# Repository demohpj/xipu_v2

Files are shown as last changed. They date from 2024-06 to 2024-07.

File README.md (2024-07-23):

# XiPU_v2

XiPU_v2 is an 8-bit 7400 TTL CPU project. It is a second iteration of the XiPU project.

## 1. About the project

The XiPU_v2 is loosely based on MOS 6502 and early x86. It was my starting point of design my own CPU. For now, the XiPU_v2 has many differences and it is so much simpler than those CPUs.

The second version of the XiPU has extended instruction set, new flat memory structure, advanced stack and function frame operations support.

The main goal of the project is creating a fully functional 8-bit 7400 TTL CPU and a simple computer based on the one.

### 1.1. Author

- Pawel Jablonski (pj@xirx.net)

### 1.2. License

You can use this code however you like but leave information about the original author. Code is free for non-commercial and commercial use.

Please see the LICENSE.txt file.

### 1.3. Links

- WWW: [xirx.net](https://xirx.net "xirx.net")
- GIT: [git.xirx.net](https://git.xirx.net "git.xirx.net")

## 2. Useful knowledge

### 2.1. Dictionary

- XiPU - XiRX Processor Unit. The name of the 8-bit TTL CPU.
- XiPU_v2 - The second iteration of the XiPU.
- XiPC - XiRX Personal Computer. The name of the simple computer based on XiPU CPU
- TTL - Transistor-transistor logic.
- HCT - High-Speed CMOS chips available in TTL compatible form.
- RAM - Volatile random access memory.
- ROM - Non-volatile read-only memory.
- Register - Quickly accessible location for a small amount of data stored in a TTL chip.
- uROM - uROM determines which of the internal registers is used to read from and write to at the current micro step of executing instruction.
- BIOS - Basic input/output system. Provides access to basic IO API and loads the OS.
- OS - Operating System. It contains a terminal interface and basic libraries.
- Stack - High accessibly memory page where data is stored as FILO.
- Function Frame - Part of the stack where arguments of the function and local variables are stored.
- IO operation - Read or write data to pins connected to external world.
- External BUS - Data highway for IO operations.
- ALU - Arithmetic logic unit.

### 2.2. XiPU_v2

- 8-bit processor based on 7400 HCT chips compatible with TTL.
- 64 kB of RAM space. Lower 2 kB are reserved for BIOS stored at EEPROM. The 4 kB at the end of the memory are used as a stack. Rest 58 kB of memory could be used by OS or applications.
- 1 MHz clock speed. The processor uses a 2 MHz crystal to get two 1 MHz square waves shifted relative to the other about half.
- The processor uses uROM stored in two EEPROMs.
- Each instruction could be built from 2 to 16 micro steps. Each micro step takes exactly 1 clock tick.
- Four registers:
	- A, B - 8-bit general purpose registers.
	- X, Y - 8-bit auxiliary registers. Could be used mostly as general purpose registers. Together, it can be used as a 16-bit address register.
- Two hidden stack registers:
	- SP - Stack Pointer. It is used to address the head of the stack.
	- BP - Base Pointer. It is used to address the function frame on the stack to store parameters of a function and local variables.
- Three internal buses:
	- BUS A - 8-bit main BUS for registers, RAM, ROM, IO operations.
	- BUS B - 8-bit auxiliary BUS for registers used as second input for ALU.
	- BUS C - 16-bit memory address BUS for addressing RAM.
- 8-bit IN and 8-bit OUT external data BUS. It is used as a simple communication way with the external word.

### 2.3. XiPC

- Personal computer based on the XiPU.
- 40x30 characters with 16 colors support. It uses 640x480 LCD with an 8-bit color palette to render image output.
- Mono speaker with a volume knob.
- RS-232 with 1200 bps support.
- RTC with battery support.
- Built-in QWERTY keyboard.
- 4 status LEDs.
- 7.5V max 1.0A power supply.

## 3. Project overview

### 3.1. Requirements

The project supports building process on Windows and Linux.

- Geany - Multi-language IDE. Used to create Makefile, assembler code etc.
- QtCreator - IDE for C++/Qt. Used to create desktop applications.
- Qt 5.12.4 - Multiplatform Qt 5 library. It supports UI, data structures, files etc.
- GCC - C and C++ code compiler.
- Keil uVision 5.37 - Compiler and debugger for the STM32F0 MCU.
- Make - Build automation tool.
- Doxygen 1.9.7 - Documentation generator from annotated sources.
- Proteus 8.10 - Circuit simulator software. Used to simulate the XiPU.
- QCAD - DXF files editor. Used to create Plexiglas case for the XiPC.
- DipTrace 4.2.0.1 - Schematic and PCB design software.

### 3.2. Project structure

```console
.
├── LICENSE.txt    # License file.
├── Makefile       # Main Makefile file to building binaries and documentations at once.
├── README.md      # Readme file.
├── bin            # Destination directory for all generated binaries during the build process.
├── case
│   ├── 3d         # A 3D printed case project for the XiPC.
│   └── plexiglass # A simple Plexiglas case project for the XiPC.
├── cpu
│   ├── bios       # BIOS with a loader and IO API for the OS.
│   ├── pcb        # PCB design for the XiPU.
│   └── sim        # Simulation project of the XiPU.
├── doc            # Destination directory for all generated documentations during the build process.
├── ide
│   ├── geany      # IDE configuration to support assembler for the XiPU.
│   └── qtcreator  # IDE configuration for code rules.
├── io
│   ├── fw         # Firmware for the IO Board.
│   └── pcb        # PCB design for the IO Board.
├── kbd
│   └── pcb        # PCB design for the Keyboard.
├── sys
│   ├── app        # Applications written for the XiPC.
│   ├── fs         # File System generator needed by the real XiPC and the XiPC Emulator.
│   └── os         # OS with a simple terminal and basic libraries for applications.
└── tools
    ├── asm        # Assembler Compiler.
    ├── emu        # XiPC Emulator.
    ├── fonts      # Fonts used in desktop GUI applications.
    ├── lib        # Binary libraries needed to run compiled applications on Windows x64.
    └── urom       # uROM generator.
```

## 4. Compiling

### 4.1. Build all

To build all binaries and create documentations for them, please type:

```console
make
```

### 4.2. Build a single module

#### 4.2.1 uROM

To build the application and create documentation, please type:

```console
cd tools/urom
make
```

#### 4.2.2. ASM Compiler

To build the application and create documentation, please type:

```console
cd tools/asm
make
```

#### 4.2.3. BIOS

To build the BIOS image file, the map file with API handlers, and create documentation, please type:

```console
cd cpu/bios
make
```

#### 4.2.4. OS

To build the OS, the map file with API handlers, please type:

```console
cd sys/os
make
```

#### 4.2.5. IO Board firmware

To build the IO Board firmware file, and create documentation, please type:

```console
cd io/fw
make
```
To build successfully a firmware is needed the Keil uVision5 with a free license for STM32F0 MCU. UV4.exe must be added to the PATH env.

#### 4.2.6. Applications

To build the user applications, please type:

```console
cd sys/app
make
```

#### 4.2.7. File System

To generate a directory with the virtual file system, please type:

```console
cd sys/fs
make
```

#### 4.2.8. XiPC Emulator

To build the application and create documentation, please type:

```console
cd tools/emu
make
```

## 5. Using

### 5.1. uROM

To generate uROM files, please type:

```console
./urom
```

### 5.2. ASM Compiler

To compile BIOS, please type:

```console
./asm bios [input_file] [output_bin] [output_map]
```

To compile OS, please type:

```console
./asm os [input_file] [output_bin] [output_map]
```

To compile an application, please type:

```console
./asm app [input_file] [output_bin]
```

#### 5.3. XiPC Emulator

To run the XiPC Emulator application, please type:

```console
./emu
```

It will show a window of the emulator ready to work. Next step is loading uROM files, BIOS file and choose the directory with the virtual file system. After that, the application is ready to run emulation.

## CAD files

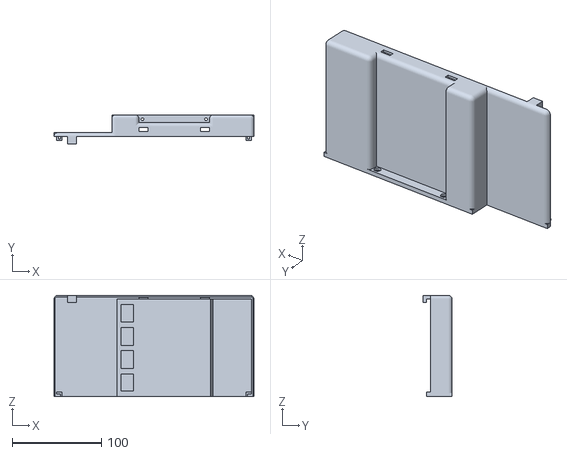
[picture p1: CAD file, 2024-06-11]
case/3d/stl/lcd_back.stl
224.6 x 32.8 x 113.5

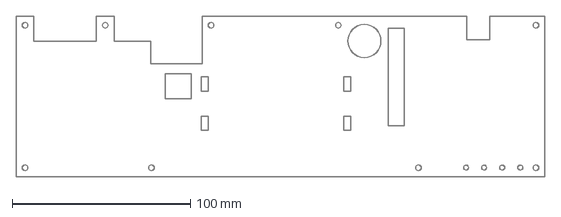
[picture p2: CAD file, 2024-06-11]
case/plexiglass/io.dxf
297.0 x 90.0 mm

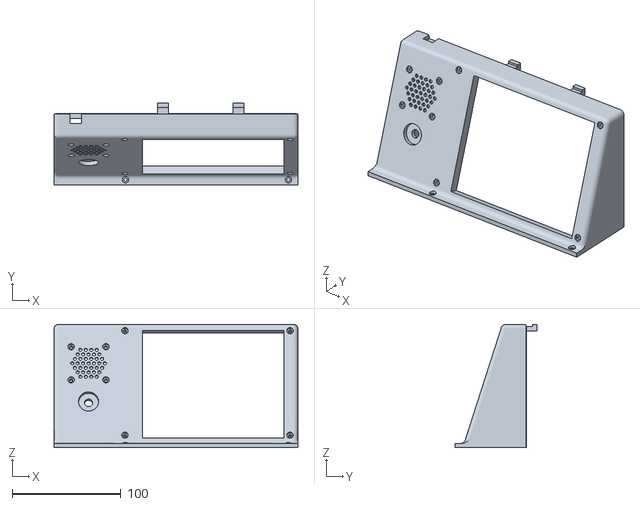
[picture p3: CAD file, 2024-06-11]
case/3d/stl/lcd_front.stl
224.6 x 75.3 x 113.5

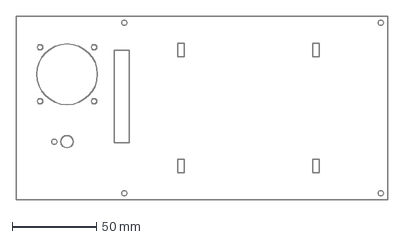
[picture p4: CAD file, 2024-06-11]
case/plexiglass/lcd.dxf
220.0 x 109.0 mm

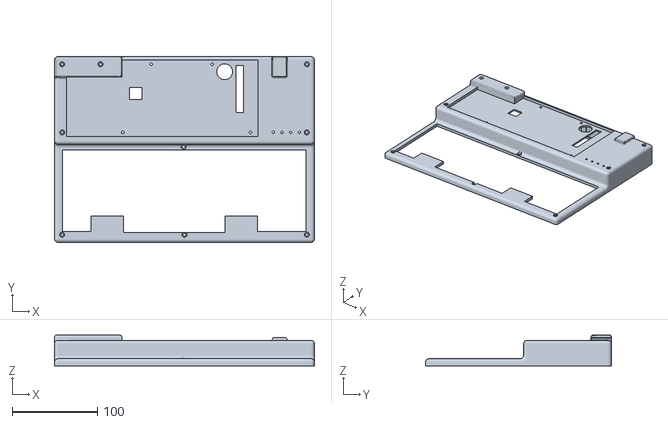
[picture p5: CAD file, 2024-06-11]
case/3d/stl/top.stl
305.0 x 218.0 x 36.0

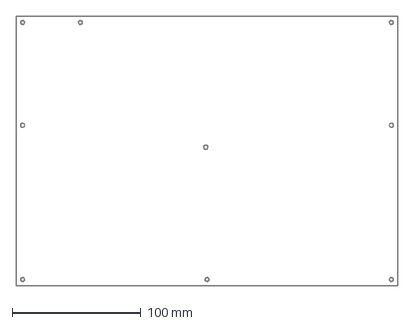
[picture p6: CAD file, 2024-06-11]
case/plexiglass/xipu.dxf
297.0 x 210.0 mm

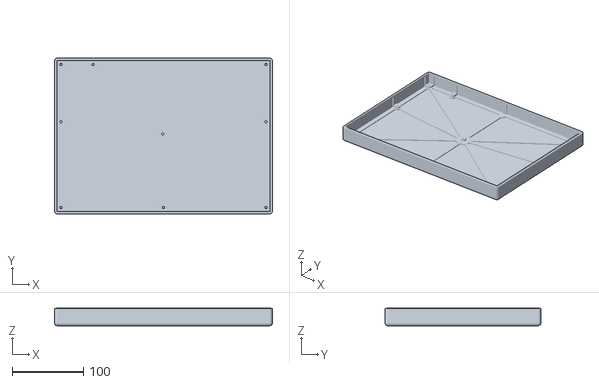
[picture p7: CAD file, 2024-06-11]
case/3d/stl/bottom.stl
305.0 x 218.0 x 24.7

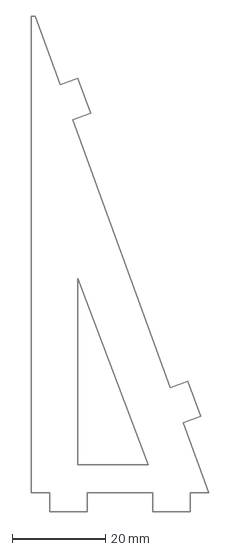
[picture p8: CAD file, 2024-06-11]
case/plexiglass/support.dxf
38.0 x 106.0 mm

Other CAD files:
case/3d/f3d/bottom.f3d
case/3d/f3d/lcd_back.f3d
case/3d/f3d/lcd_front.f3d
case/3d/f3d/top.f3d

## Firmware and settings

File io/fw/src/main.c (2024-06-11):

/*
 * Author: Pawel Jablonski
 * E-mail: pj@xirx.net
 * WWW: xirx.net
 * GIT: git.xirx.net
 *
 * License: You can use this code however you like
 * but leave information about the original author.
 * Code is free for non-commercial and commercial use.
 */

#include <stm32f0xx.h>
#include <stm32f0xx_hal.h>
#include <stm32f0xx_hal_gpio.h>
#include <stm32f0xx_hal_rcc.h>
#include <system_stm32f0xx.h>

#include "type.h"
#include "led.h"
#include "rtc.h"
#include "keyboard.h"
#include "speaker.h"
#include "lcd.h"
#include "flash.h"
#include "io.h"
#include "rs232.h"
#include "usb.h"
#include "fs.h"

bool initIsEnded = FALSE; //!< Status of end initializing all devices

//! Init main clock
static void initClock(void)
{
	RCC_OscInitTypeDef oscInit;

	oscInit.OscillatorType = (RCC_OSCILLATORTYPE_HSE | RCC_OSCILLATORTYPE_LSE);
	oscInit.HSEState = RCC_HSE_ON;
	oscInit.HSICalibrationValue = 16;
	oscInit.LSEState = RCC_LSE_ON;
	oscInit.PLL.PLLState = RCC_PLL_ON;
	oscInit.PLL.PLLSource = RCC_PLLSOURCE_HSE;
	oscInit.PLL.PLLMUL = RCC_PLL_MUL6;
	oscInit.PLL.PREDIV = RCC_PREDIV_DIV1;
	
	if(HAL_RCC_OscConfig(&oscInit) != HAL_OK)
	{
		while(1);
	}
	
	RCC_ClkInitTypeDef clkInit;
	
	clkInit.ClockType = (RCC_CLOCKTYPE_SYSCLK | RCC_CLOCKTYPE_HCLK | RCC_CLOCKTYPE_PCLK1);
	clkInit.SYSCLKSource = RCC_SYSCLKSOURCE_PLLCLK;
	clkInit.AHBCLKDivider = RCC_SYSCLK_DIV1;
	clkInit.APB1CLKDivider = RCC_HCLK_DIV1;
	
	if(HAL_RCC_ClockConfig(&clkInit, FLASH_LATENCY_1) != HAL_OK)
	{
		while(1);
	}

	__HAL_RCC_SYSCFG_CLK_ENABLE();
	
	HAL_SYSTICK_Config(HAL_RCC_GetHCLKFreq() / 1000);
	HAL_SYSTICK_CLKSourceConfig(SYSTICK_CLKSOURCE_HCLK);

	HAL_NVIC_SetPriority(SysTick_IRQn, 0, 0);
}

//! Main clock ticks handler. It executes a fire function if the time counter reach maximum delay for connected device.
void SysTick_Handler(void)
{	
	HAL_IncTick();
	
	if(initIsEnded)
	{
		static unsigned long long time = 0;
		
		if((time % KEYBOARD_FIRE_DELAY) == 0) keyboardFire();
		if((time % IO_FIRE_CLOCK_DELAY) == 0) ioFireClock();
		if((time % IO_FIRE_PERIPHERIAL_DELAY) == 0) ioFirePeripherial();

		time++;
	}
}

//! Main entry function of the firmware
int main(void)
{
	HAL_Init();
	
	initClock();
	
	ioPreInit();
	
	ledInit();
	rtcInit();
	keyboardInit();
	speakerInit();
	lcdInit();
	flashInit();
	rs232Init();
	usbInit();
	fsInit();
	ioInit();
	
	initIsEnded = TRUE;
	
	lcdDrawLoop();
	
	// Do not allow returning from the main function
	while(TRUE);
		
	return(0);
}

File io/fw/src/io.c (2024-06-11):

/*
 * Author: Pawel Jablonski
 * E-mail: pj@xirx.net
 * WWW: xirx.net
 * GIT: git.xirx.net
 *
 * License: You can use this code however you like
 * but leave information about the original author.
 * Code is free for non-commercial and commercial use.
 */

#include <stm32f0xx.h>
#include <stm32f0xx_hal.h>
#include <stm32f0xx_hal_gpio.h>
#include <stm32f0xx_hal_rcc.h>
#include <system_stm32f0xx.h>

#include "type.h"
#include "keyboard.h"
#include "led.h"
#include "lcd.h"
#include "rs232.h"
#include "rtc.h"
#include "speaker.h"
#include "fs.h"

#include "io.h"

#define HALF_LOW FALSE //!< Low half of data transfer
#define HALF_HIGH TRUE //!< High half of data transfer

#define MODE_REG_SELECT FALSE //!< Register select mode
#define MODE_DATA_TRANSFER TRUE //!< Data transfer mode

#define RW_READ FALSE //!< Read data mode
#define RW_WRITE TRUE //!< Write data mode

//! Register addresses
enum RegAddress
{
	REG_COMMAND = 0, //!< Command register
	REG_STATUS = 1, //!< Status register
	REG_FIELD_ADDRESS = 2, //!< Field address register
	REG_FIELD = 3, //!< Field data register
	REG_KEYBOARD = 4, //!< Keyboard register
	REG_LCD_COLOR = 5, //!< LCD color register
	REG_LCD_CURSOR_POS_X = 6, //!< LCD cursor horizontal position register
	REG_LCD_CURSOR_POS_Y = 7, //!< LCD cursor vertical position register
	REG_LCD_CHAR = 8, //!< LCD char register
	REG_RS232 = 9, //!< RS232 register
	REG_FS = 10 //!< File System register
};

//! Low part commands
enum CommandLow
{
	FS_OPEN_OS = 0, //!< Open OS file command
	FS_RESET_NAME = 1, //!< Reset name buffer command
	FS_OPEN_APP = 2, //!< Open an application command
	FS_OPEN_FILE = 3, //!< Open a file command
	FS_LIST_APP = 4, //!< List files in the app directory
	FS_LIST_FILE = 5 //!< List files in the file sirectory
};

//! High part commands
enum CommandHigh
{
	LED_RUN_OFF = 0, //!< Turn off the run LED
	LED_RUN_ON = 1, //!< Turn on the run LED
	LED_ERROR_OFF = 2, //!< Turn off the error LED
	LED_ERROR_ON = 3, //!< Turn on the error LED
	LCD_CLEAR = 4, //!< Clear the LCD content
	LCD_REFRESH = 5, //!< Refresh the LCD content
	LCD_SCROLL_DOWN = 6, //!< Scroll down one line the LCD content
	LCD_NEW_LINE = 7, //!< Move the cursor one position down
	RTC_WRITE = 8, //!< Write the date and time buffer to the RTC
	RTC_READ = 9, //!< Read from the RTC to the date and time buffer
	SPEAKER_PLAY = 11, //!< Start playing sound
	SPEAKER_PAUSE = 12, //!< Pause playing sound
	SPEAKER_CLEAR = 13, //!< Clear the sound buffer
	SPEAKER_ADD_NOTE = 14, //!< Add a note to the sound buffer
	SPEAKER_GET_BUFFER_FREE = 15 //!< Get a free space size in the sound buffer
};

//! Low part statuses
enum StatusLow
{
	FS_STATUS = 0 //!< Status of the last FS operation
};

//! High part statuses
enum StatusHigh
{
	LED_RUN_ENABLED = 0, //!< Status of enable the run LED
	LED_ERROR_ENABLED = 1, //!< Status of enable the error LED
	SPEAKER_IS_PLAYING = 2 //!< Status of playing
};

//! Readable and writable fields
enum FieldRW
{
	RTC_YEAR = 4, //!< RTC year field
	RTC_MONTH = 5, //!< RTC month field
	RTC_DAY = 6, //!< RTC day field
	RTC_HOUR = 7, //!< RTC hour field
	RTC_MINUTE = 8, //!< RTC minute field
	RTC_SECOND = 9 //!< RTC second field
};

//! Writable fields
enum FieldW
{
	SPEAKER_NOTE = 12, //!< Code of a note to play field
	SPEAKER_TIME = 13, //!< Play time of a note field
	SPEAKER_FILL = 14, //!< Square fill of a note field
	SPEAKER_VOLUME = 15 //!< Volume of a note field
};

//! Readable fields
enum FieldR
{
	FS_DATA_SIZE_LOW = 0, //!< Low byte of a file size field
	FS_DATA_SIZE_HIGH = 1, //!< High byte of a file size field
	SPEAKER_BUFFER_FREE = 12 //!< Free space size in the sound buffer field
};

static unsigned char regSelected = 0; //!< Current selected register

//!< This struct contains motherboard's virtual registers buffer
struct
{
	unsigned char statusAddress; //!< Select a status register
	unsigned char fieldAddress; //!< Select a field register
	struct RTCDateTime rtc; //!< RTC data buffer
	struct
	{
		struct SpeakerNote note; //!< Note parameters buffer
		unsigned char bufferFree; //!< Free space size in the sound buffer
	} speaker; //!< Speaker data buffer
	struct
	{
		char name[FS_PATH_MAX_LENGTH + 1]; //!< Path buffer
		unsigned char nameLength; //!< Length of the path buffer
		struct FSSize size; //!< Size buffer
		bool status; //!< Status buffer
	} fs; //!< File System buffer
} static reg = {0};

static unsigned char ioReadStatus(bool half);
static unsigned char ioReadField(void);
static unsigned char ioReadKeyboard(bool half);
static unsigned char ioReadLCDCursorPosX(bool half);
static unsigned char ioReadLCDCursorPosY(bool half);
static unsigned char ioReadRS232Rx(bool half);
static unsigned char ioReadFSData(bool half);

static void ioWriteCommand(bool half, unsigned char dataInRaw);
static void ioWriteStatusAddress(unsigned char dataInRaw);
static void ioWriteFieldAddress(unsigned char dataInRaw);
static void ioWriteField(bool half, unsigned char dataIn, unsigned char mask);
static void ioWriteLCDColor(bool half, unsigned char dataInRaw);
static void ioWriteLCDCursorPosX(bool half, unsigned char dataIn, unsigned char mask);
static void ioWriteLCDCursorPosY(bool half, unsigned char dataIn, unsigned char mask);
static void ioWriteLCDChar(bool half, unsigned char dataIn, unsigned char mask);
static void ioWriteCRS232Tx(bool half, unsigned char dataIn, unsigned char mask);
static void ioWriteFSName(bool half, unsigned char dataIn, unsigned char mask);

static void ioCreatePath(char *buffer, const char *dirName, const char *fileName);

//! First stage of init. It set up all IO pins. It must be executed before all devices init.
void ioPreInit(void)
{
	GPIO_InitTypeDef gpioInit = {0};
	
	__HAL_RCC_GPIOB_CLK_ENABLE();
	
	gpioInit.Pin = (GPIO_PIN_8 | GPIO_PIN_9 | GPIO_PIN_10 | GPIO_PIN_11 | GPIO_PIN_12 | GPIO_PIN_13 | GPIO_PIN_14);
	gpioInit.Mode = GPIO_MODE_INPUT;
	gpioInit.Pull = GPIO_PULLDOWN;
	gpioInit.Speed = GPIO_SPEED_FREQ_HIGH;
	
	HAL_GPIO_Init(GPIOB, &gpioInit);
	
	gpioInit.Pin = (GPIO_PIN_0 | GPIO_PIN_1 | GPIO_PIN_2 | GPIO_PIN_3 | GPIO_PIN_4 | GPIO_PIN_5 | GPIO_PIN_6 | GPIO_PIN_7);
	gpioInit.Mode = GPIO_MODE_OUTPUT_PP;
	gpioInit.Pull = GPIO_NOPULL;
	gpioInit.Speed = GPIO_SPEED_FREQ_HIGH;
	
	HAL_GPIO_Init(GPIOB, &gpioInit);
	
	HAL_GPIO_WritePin(GPIOB, GPIO_PIN_0, GPIO_PIN_RESET);
	HAL_GPIO_WritePin(GPIOB, GPIO_PIN_1, GPIO_PIN_RESET);
	HAL_GPIO_WritePin(GPIOB, GPIO_PIN_2, GPIO_PIN_RESET);
	HAL_GPIO_WritePin(GPIOB, GPIO_PIN_3, GPIO_PIN_RESET);
	HAL_GPIO_WritePin(GPIOB, GPIO_PIN_4, GPIO_PIN_RESET);
	HAL_GPIO_WritePin(GPIOB, GPIO_PIN_5, GPIO_PIN_RESET);
	HAL_GPIO_WritePin(GPIOB, GPIO_PIN_6, GPIO_PIN_RESET);
	HAL_GPIO_WritePin(GPIOB, GPIO_PIN_7, GPIO_PIN_RESET);
}
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

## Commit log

2024-02-14 Add an assembler compilator
2024-06-10 Fix two bank flag switching issue in the XiPU simulation
2024-06-10 Add RUN LED on during boot in the BIOS
2024-06-10 Add enabling RUN LED on during load app in the OS
2024-06-10 Change the ST instruction definition in the assembler compilator
2024-06-10 Fix bad memory access issue in the assembler compilator
2024-06-11 Add a XiPC IO Board firmware
2024-06-11 Add a PCB schematic for the XiPC IO Board
2024-06-11 Add a PCB schematic for the XiPC Keyboard Board
2024-06-11 Add a PCB schematic for the XiPU
2024-06-11 Add a plexiglass case for the XiPC
    [io.dxf, lcd.dxf, support.dxf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]
2024-06-11 Add a 3D printed case for the XiPC
    [bottom.f3d, bottom.stl, lcd_back.f3d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]
2024-08-01 Remove duplicates of instructions in the assembler language definition file for Geany
